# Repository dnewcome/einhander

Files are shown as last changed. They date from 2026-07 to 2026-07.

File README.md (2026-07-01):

# einhander

A one-handed hardware controller for music performance and sequencing — MC-303-inspired,
simplicity-first. Two rows of four key switches under the fingers, a thumbwheel + SHIFT on
the side for the thumb, so the other hand stays free for sliders/faders.

This repo holds the **code-driven** design: a parametric enclosure (build123d) and a
fabbable PCB (tscircuit → KiCad).

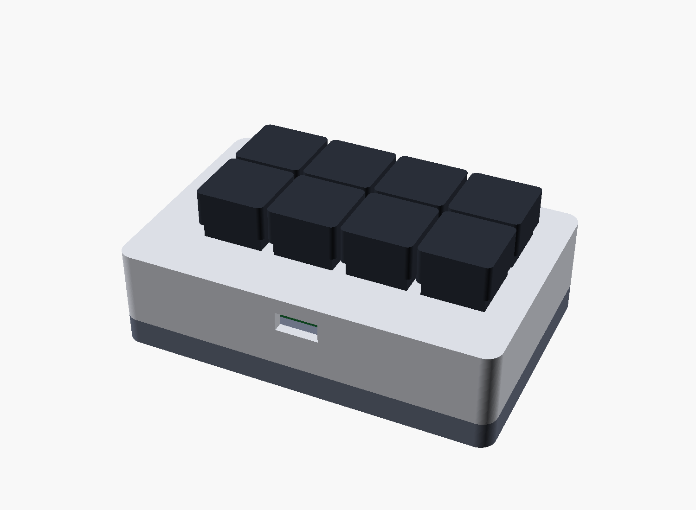
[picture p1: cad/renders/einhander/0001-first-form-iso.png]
einhander enclosure — isometric render


## What's here

```
cad/    parametric enclosure — build123d (machine_params.py = single source of truth),
        top/bottom shells + component stand-ins, assembly + dated render log
pcb/    RP2040 USB-MIDI controller board
          index.circuit.tsx        composes the board (flat, global nets)
          modules/                 mcu (RP2040+flash+xtal+decoupling), power (USB-C+LDO)
          lib/, imports/           shared params, custom Cherry-MX footprint, JLC parts
          scripts/                 route4.sh + the 4-layer routing toolchain
          index.circuit.kicad_pcb  routed 4-layer board
          fab/                     Gerbers + drill + CPL  (einhander-gerbers.zip → upload to JLCPCB)
```

## The board

- **RP2040**, pure **USB-MIDI** controller (class-compliant, no drivers), wired USB-C
- 8 MX key switches on direct GPIO; EC11 thumbwheel + SHIFT broken out to a header for a
  left-wall daughterboard; one WS2812 status LED; BOOTSEL/RESET
- **4-layer**: signals on outer layers, dedicated **GND + 3V3 inner planes**
- **DRC-clean**, ~91 × 68 mm

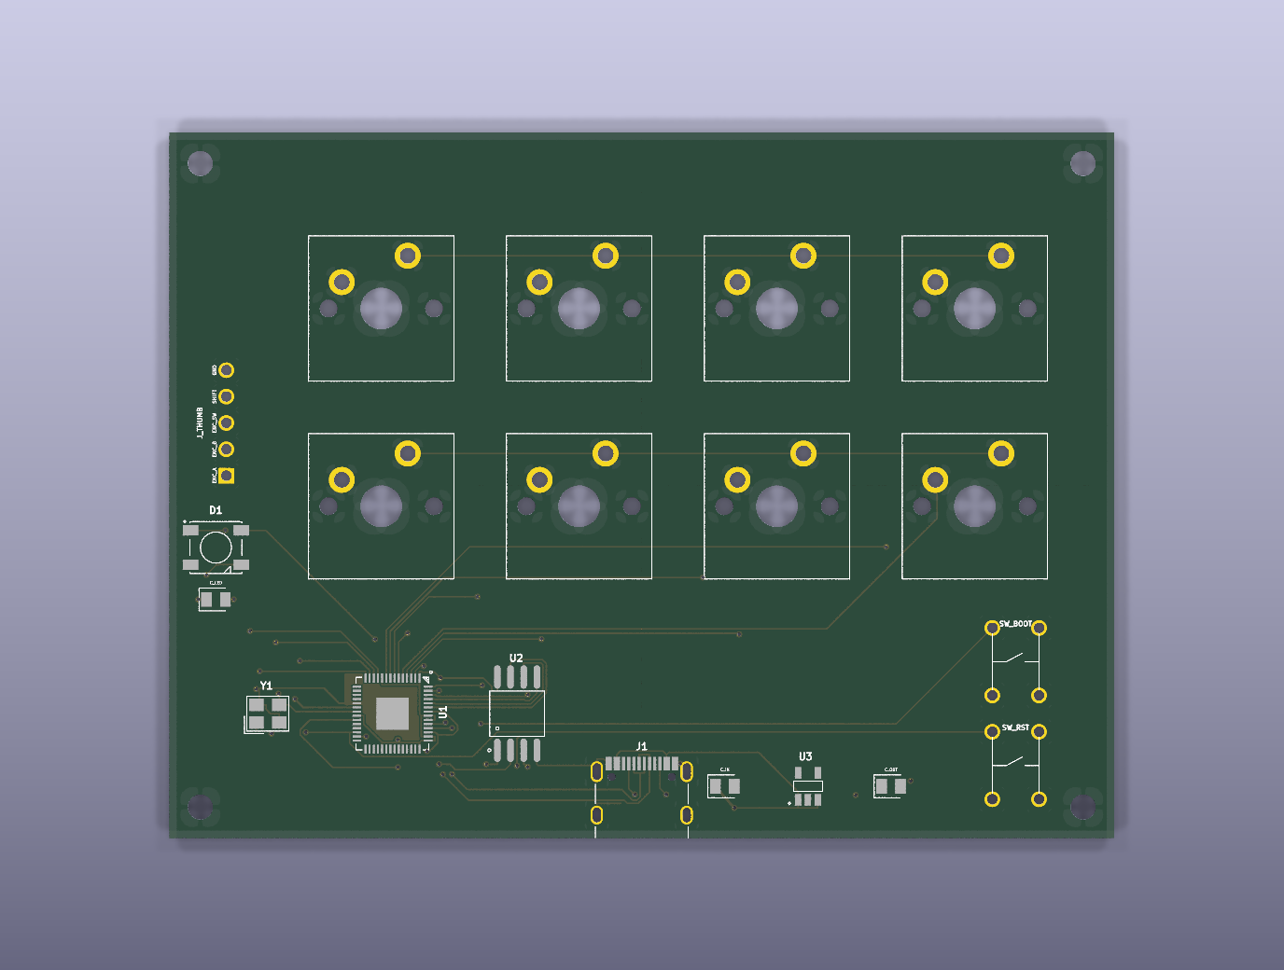
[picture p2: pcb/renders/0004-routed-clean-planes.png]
Routed 4-layer PCB


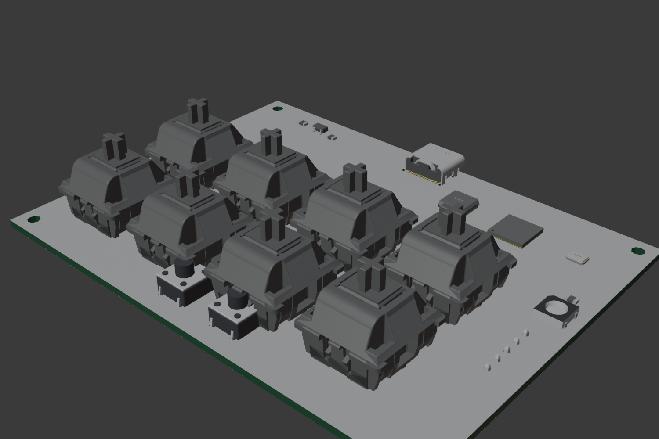
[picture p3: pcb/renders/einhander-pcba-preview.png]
Populated board (PCBA) with Cherry MX switches


Interactive 3D model of the populated board: **`pcb/renders/einhander-pcba.glb`** (open in any glTF viewer — Blender, VS Code glTF, or https://gltf-viewer.donmccurdy.com).

### Fabricating it

Upload `pcb/fab/einhander-gerbers.zip` to [JLCPCB](https://jlcpcb.com) (select **4 layers**). For
assembly, add `pcb/fab/einhander-bom.csv` (27 SMD parts, LCSC-mapped) + `pcb/fab/einhander-cpl.csv`
(placement). MX switches, the EC11 thumbwheel, headers, and BOOT/RESET tactiles are **hand-soldered**
(listed separately in `einhander-handsolder.csv`, kept out of the assembly BOM).

**PCBWay** uses the same `einhander-gerbers.zip` + `einhander-cpl.csv`, with `einhander-bom-pcbway.csv`
(sources by manufacturer part number instead of LCSC). `make_fab.sh` emits both BOM formats. Regenerate the whole bundle with `bash pcb/scripts/make_fab.sh pcb/index.circuit.kicad_pcb einhander`.

### Regenerating

```bash
# enclosure
cd cad && python3 machine.py            # STLs + renders

# PCB (needs bun/tscircuit, KiCad 9, Freerouting v2.2.4 + JDK 25)
cd pcb && npm install
bash scripts/route4.sh                  # export → route (4-layer) → inject → DRC
```

## Status

Enclosure prototype ✅ · Routed 4-layer PCB ✅ (fab-ready) · thumb-cluster daughterboard, RP2040
firmware (TinyUSB MIDI), and an enclosure↔board fit re-sync are next.

---
Designed with [Claude Code](https://claude.com/claude-code).

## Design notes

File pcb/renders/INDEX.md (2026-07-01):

- 0001-placement.png — 2026-06-30 — first valid placement (RP2040 USB-MIDI controller)
- 0002-routed-4layer.png — 2026-06-30 — 4-layer routed (v2.2.4): 256 wires, inner GND/V3V3 planes
- 0003-routed-clean.png — 2026-06-30 — CLEAN DRC (0 shorts/unconn), 4-layer
- 0004-routed-clean-planes.png — 2026-07-01 — 4-layer clean: GND/V3V3 planes, RP2040 local GND pour, NPTH keepouts (no traces through keyswitch holes), DRC clean

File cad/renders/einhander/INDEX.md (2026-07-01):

- 0001-first-form — 2026-06-30 — first-form

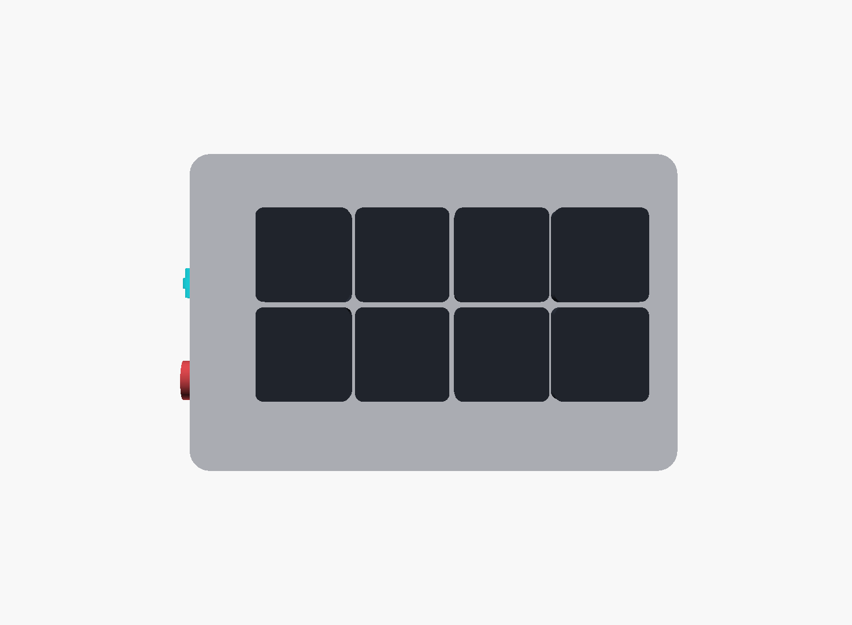
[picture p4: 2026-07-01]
cad/renders/einhander/0001-first-form-top.png

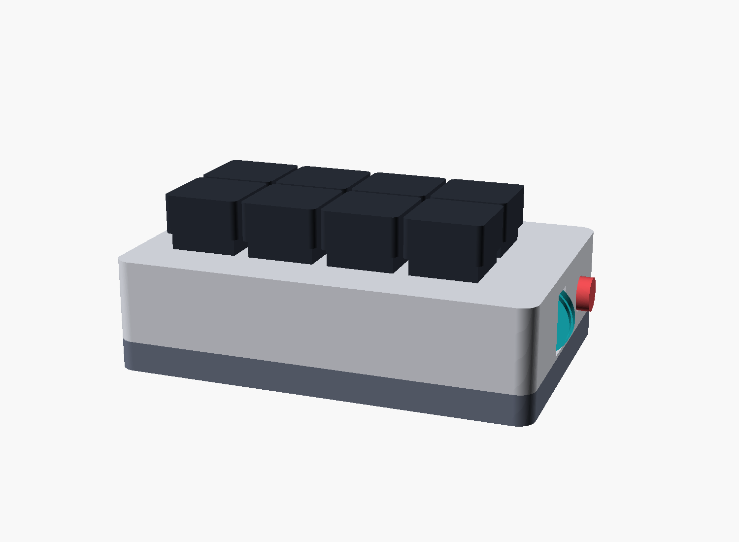
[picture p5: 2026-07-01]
cad/renders/einhander/0001-first-form-thumb.png

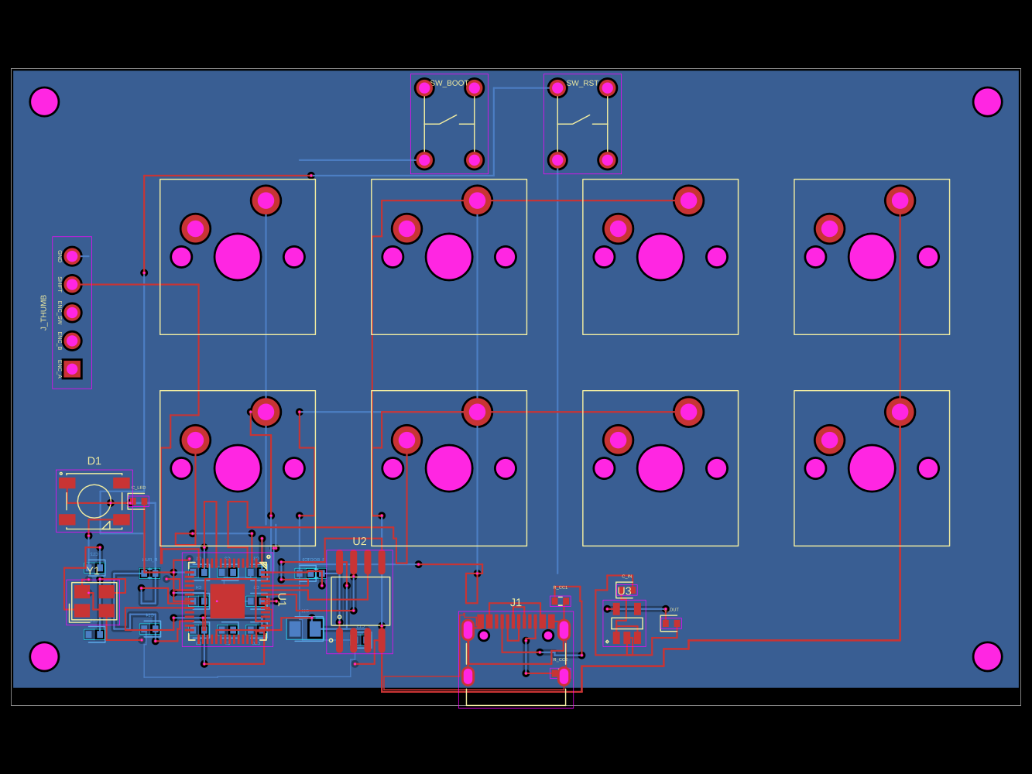
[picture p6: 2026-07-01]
pcb/renders/0001-placement.png

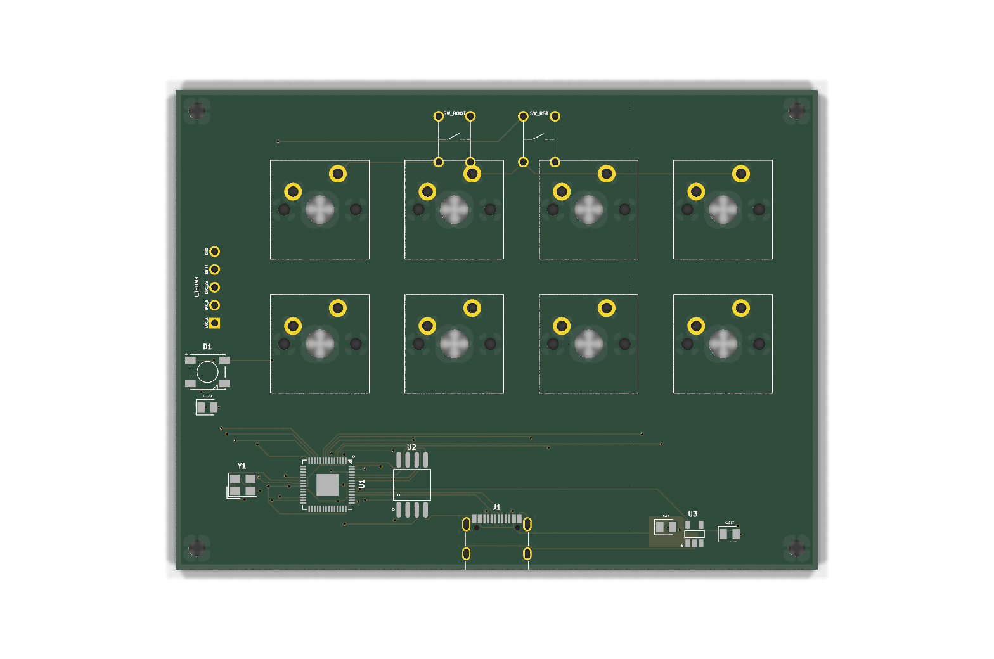
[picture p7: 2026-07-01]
pcb/renders/0003-routed-clean.png

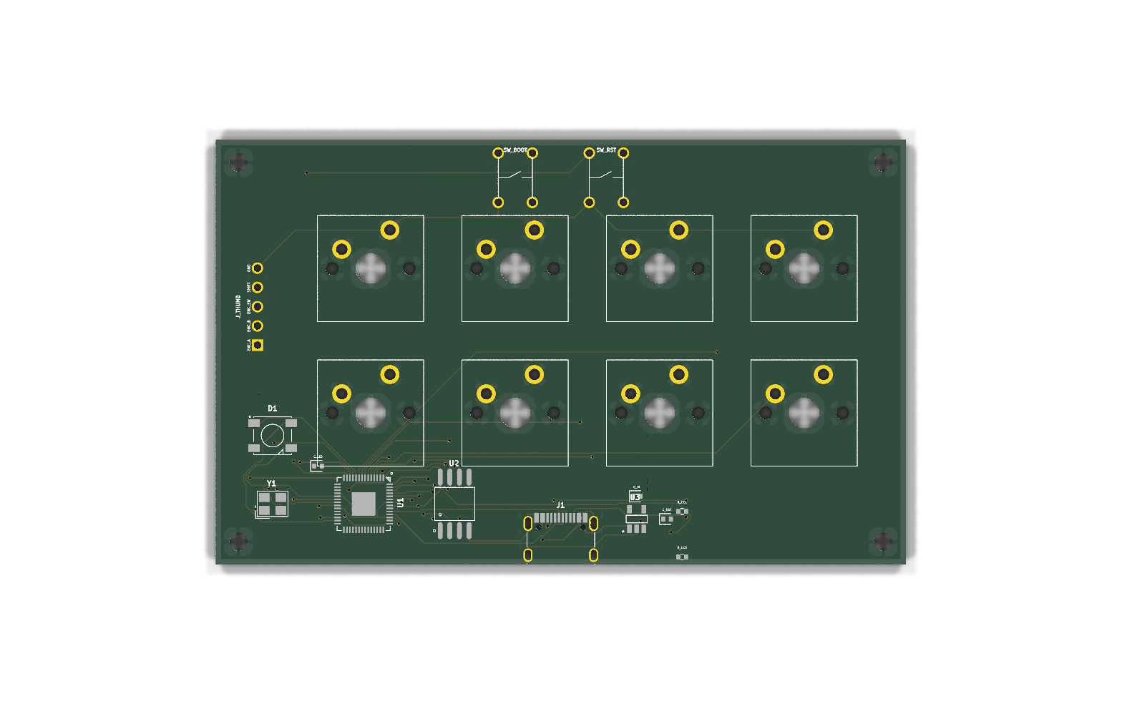
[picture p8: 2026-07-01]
pcb/renders/0002-routed-4layer.png

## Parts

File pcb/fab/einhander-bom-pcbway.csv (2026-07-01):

Item# | Designator | Qty | Comment | Footprint | Manufacturer Part Number | Manufacturer | LCSC Part No
1 | C1,C10,C14,C15,C2,C3,C4,C5,C6,C7 | 10 | 100nF | capacitor_0402 | CL05B104KO5NNNC | Samsung Electro-Mechanics | C1525
2 | C11 | 1 | 10uF | capacitor_0805 | CL21A106KAYNNNE | Samsung Electro-Mechanics | C15850
3 | C12,C13 | 2 | 15pF | capacitor_0402 | 0402CG150J500NT | FH (Guangdong Fenghua) | C1548
4 | C9 | 1 | 1uF | capacitor_0402 | CL05A105KA5NQNC | Samsung Electro-Mechanics | C52923
5 | C_LED | 1 | 100nF | capacitor_0805 | CC0805KRX7R9BB104 | YAGEO | C49678
6 | C_IN,C_OUT | 2 | 1uF | capacitor_0805 | CL21B105KBFNNNE | Samsung Electro-Mechanics | C28323
7 | D1 | 1 | WS2812B_B_T | WS2812B_B_T | WS2812B-B/T | Worldsemi | C2761795
8 | J1 | 1 | TYPE_C_31_M_12 | TYPE_C_31_M_12 | TYPE-C-31-M-12 | Korean Hroparts Elec | C165948
9 | R_RUN | 1 | 10k | resistor_res0402 | 0402WGF1002TCE | UNI-ROYAL(Uniroyal Elec) | C25744
10 | R_BOOT | 1 | 1k | resistor_res0402 | 0402WGF1001TCE | UNI-ROYAL(Uniroyal Elec) | C11702
11 | R_CC1,R_CC2 | 2 | 5.1k | resistor_res0402 | 0402WGF5101TCE | UNI-ROYAL(Uniroyal Elec) | C25905
12 | U1 | 1 | RP2040 | RP2040 | RP2040 | Raspberry Pi | C2040
13 | U2 | 1 | W25Q16JVSSIQ | W25Q16JVSSIQ | W25Q16JVSSIQ | Winbond | C131025
14 | U3 | 1 | AP2112K_3_3TRG1 | AP2112K_3_3TRG1 | AP2112K-3.3TRG1 | Diodes Incorporated | C51118
15 | Y1 | 1 | X322512MSB4SI | X322512MSB4SI | X322512MSB4SI | YXC | C9002

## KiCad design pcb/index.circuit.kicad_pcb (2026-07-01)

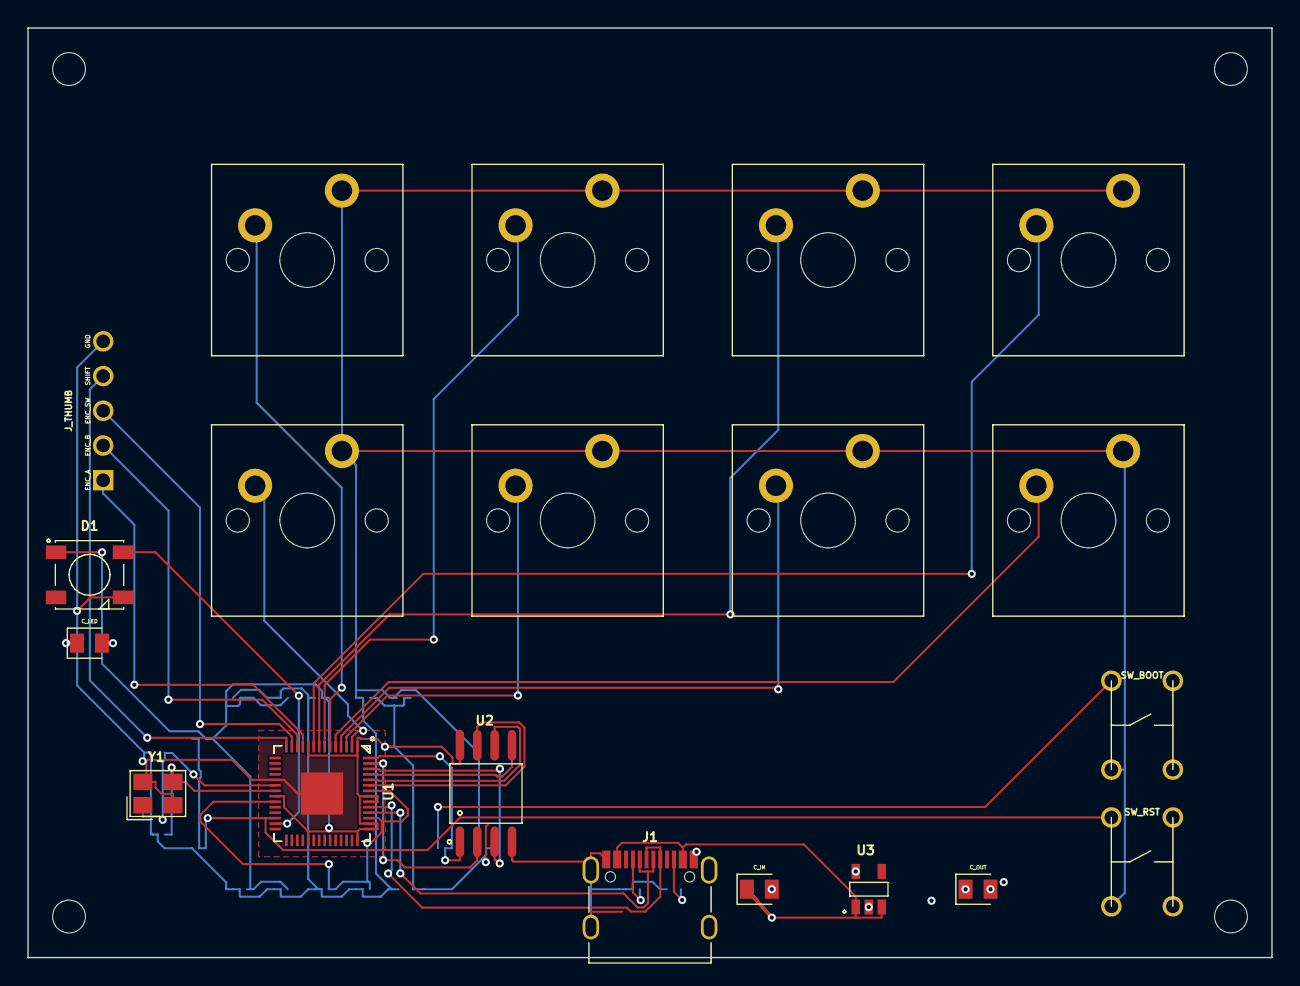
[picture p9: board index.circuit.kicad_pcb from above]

Board: 4 copper layers, 91.0 x 68.0 mm, 38 parts (0 on the bottom side), 31 nets.

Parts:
C1, C2, C3, C4, C5, C6, C7, C10, C14, C15: 100nF; capacitor_0402
C9: 1uF; capacitor_0402
C11: 10uF; capacitor_0805
C12, C13: 15pF; capacitor_0402
C_IN: 1uF; capacitor_0805
C_LED: 100nF; capacitor_0805
C_OUT: 1uF; capacitor_0805
D1: WS2812B_B_T
J1: TYPE_C_31_M_12
J_THUMB: J_THUMB; pin_header_pinrow5
R_BOOT: 1kΩ; resistor_res0402
R_CC1, R_CC2: 5.1kΩ; resistor_res0402
R_RUN: 10kΩ; resistor_res0402
SW1, SW2, SW3, SW4, SW5, SW6, SW7, SW8: chip
SW_BOOT: SW_BOOT; push_button_pushbutton
SW_RST: SW_RST; push_button_pushbutton
U1: RP2040
U2: W25Q16JVSSIQ
U3: AP2112K_3_3TRG1
Y1: X322512MSB4SI

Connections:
BOOT_BTN: R_BOOT.2, SW_BOOT.1
DVDD: C9.1, C10.1, U1.23, U1.45, U1.50
ENC_A: J_THUMB.1, U1.11
ENC_B: J_THUMB.2, U1.12
ENC_SW: J_THUMB.3, U1.13
GND: C1.2, C2.2, C3.2, C4.2, C5.2, C6.2, C7.2, C9.2, C10.2, C11.2, C12.2, C13.2, C14.2, C15.2, C_IN.2, C_LED.2, C_OUT.2, D1.3, J1.1, J1.2, J1.3, J1.4, J1.13, J1.14, J_THUMB.5, R_CC1.2, R_CC2.2, SW1.2, SW2.2, SW3.2, SW4.2, SW5.2, SW6.2, SW7.2, SW8.2, SW_BOOT.2, SW_RST.2, U1.19, U1.57, U2.4, U3.2, Y1.2, Y1.4
J1.A5 to R_CC1.pin1: J1.6, R_CC1.1
J1.B5 to R_CC2.pin1: J1.12, R_CC2.1
KEY0: SW1.1, U1.2
KEY1: SW2.1, U1.3
KEY2: SW3.1, U1.4
KEY3: SW4.1, U1.5
KEY4: SW5.1, U1.6
KEY5: SW6.1, U1.7
KEY6: SW7.1, U1.8
KEY7: SW8.1, U1.9
LED_DIN: D1.4, U1.27
QSPI_SCLK: U1.52, U2.6
QSPI_SD0: U1.53, U2.5
QSPI_SD1: U1.55, U2.2
QSPI_SD2: U1.54, U2.3
QSPI_SD3: U1.51, U2.7
QSPI_SS: R_BOOT.1, U1.56, U2.1
RUN: C14.1, R_RUN.2, SW_RST.1, U1.26
SHIFT: J_THUMB.4, U1.14
USB_DM: J1.7, J1.9, U1.46
USB_DP: J1.8, J1.10, U1.47
V3V3: C1.1, C2.1, C3.1, C4.1, C5.1, C6.1, C7.1, C11.1, C15.1, C_LED.1, C_OUT.1, D1.1, R_RUN.1, U1.1, U1.10, U1.22, U1.33, U1.42, U1.43, U1.44, U1.48, U1.49, U2.8, U3.5
VBUS: C_IN.1, J1.15, J1.16, U3.1, U3.3
XIN: C12.1, U1.20, Y1.1
XOUT: C13.1, U1.21, Y1.3

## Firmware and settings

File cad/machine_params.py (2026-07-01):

"""einhander — one-handed groovebox / MIDI controller.

SINGLE SOURCE OF TRUTH for every shared dimension + the place() mate helper.
Nothing downstream re-types a number that lives here.

Coordinate convention (world frame, right-handed device):
    +X = across the four fingers (column direction). Right = pinky side.
    +Y = "front" (away from palm, where the fingertips reach).
    -Y = "back"  (palm / wrist side).
    +Z = up (out of the top deck).
    World z=0 = underside of the bottom tray. Device grows upward.

Grip model: held in the right hand like a bar. Four fingers curl over the
back edge onto the 2x4 key deck (one column per finger, near/far per row).
The thumb wraps the LEFT (-X) wall and works the thumbwheel + SHIFT button.
"""

from math import sqrt
from build123d import Location, Pos, Rot  # noqa: F401  (re-exported for parts)


def place(solid, frm: Location, onto: Location):
    """Snap `solid` so its local mate `frm` coincides with world Location `onto`."""
    return (onto * frm.inverse()) * solid


# ---------------------------------------------------------------- key matrix
KEY_COLS = 4            # across the fingers (X)
KEY_ROWS = 2            # near / far per finger (Y)
KEY_PITCH = 19.05       # MX standard 0.75"
KEY_CUTOUT = 14.0       # MX plate cutout (square)
KEYCAP = 18.0           # 1u keycap footprint
KEYCAP_H = 9.0          # keycap height above deck
SWITCH_BODY = 15.6      # MX upper housing
SWITCH_BELOW = 5.0      # housing depth below deck top -> sets PCB plane

# center-to-center span of the matrix
KEYFIELD_X = (KEY_COLS - 1) * KEY_PITCH      # 57.15
KEYFIELD_Y = (KEY_ROWS - 1) * KEY_PITCH      # 19.05

# ---------------------------------------------------------------- body / shell
MARGIN_L = 12.0   # left (thumb) margin: keycap edge -> inner wall (wheel room)
MARGIN_R = 5.0    # right (pinky) margin
MARGIN_F = 9.0    # front margin
MARGIN_B = 24.0   # back (palm) margin — enlarged for the MCU band / routing room
WALL = 2.5
DECK_T = 1.5      # top plate thickness (MX snap-fit needs ~1.5)
FLOOR_T = 2.0

# inner cavity, centered on the body origin
CAV_X = KEYFIELD_X + KEYCAP + MARGIN_L + MARGIN_R
CAV_Y = KEYFIELD_Y + KEYCAP + MARGIN_F + MARGIN_B
BODY_X = CAV_X + 2 * WALL
BODY_Y = CAV_Y + 2 * WALL

# the matrix is pushed off-center so the thumb side gets the extra room
KEY_CENTER_X = (MARGIN_L - MARGIN_R) / 2.0   # +ve -> matrix shifts toward pinky
KEY_CENTER_Y = (MARGIN_B - MARGIN_F) / 2.0   # +ve -> matrix shifts toward front

# ---------------------------------------------------------------- heights
H_TOTAL = 26.0                     # shell height (keycaps extra)
SEAM_Z = 7.0                       # split plane: bottom tray height
H_BOT = SEAM_Z                     # bottom shell height
H_TOP = H_TOTAL - SEAM_Z           # top shell height (19)

DECK_TOP_Z = H_TOTAL                       # world z of deck top face
DECK_UNDER_Z = H_TOTAL - DECK_T            # 24.5
PCB_T = 1.6
PCB_TOP_Z = DECK_UNDER_Z - SWITCH_BELOW    # 19.5  (switch sits on plate, solders to PCB)
PCB_BOT_Z = PCB_TOP_Z - PCB_T


def key_xy(col, row):
    """World (x, y) of a switch center."""
    x = KEY_CENTER_X + (col - (KEY_COLS - 1) / 2.0) * KEY_PITCH
    y = KEY_CENTER_Y + (row - (KEY_ROWS - 1) / 2.0) * KEY_PITCH
    return x, y


KEY_XY = [key_xy(c, r) for r in range(KEY_ROWS) for c in range(KEY_COLS)]

# ---------------------------------------------------------------- thumb cluster (left wall)
WHEEL_R = 8.0          # dia 16 thumbwheel
WHEEL_T = 6.0          # rim width (along Y)
WHEEL_PROTRUDE = 2.5   # how far the rim pokes past the outer wall (-X)
WHEEL_Y = 6.0          # toward front
WHEEL_Z = 15.0         # mid-height
# wheel axis runs along Y (front-back); thumb rolls it up/down through a side slot
WHEEL_CX = -BODY_X / 2 + (WHEEL_R - WHEEL_PROTRUDE)   # disc center x (inside)

# slot in the left wall: narrow in Y (rim width), tall in Z (exposed chord)
WHEEL_SLOT_W = WHEEL_T + 1.5
WHEEL_SLOT_H = 2 * sqrt(WHEEL_R**2 - (WHEEL_R - WHEEL_PROTRUDE) ** 2) + 2.5

BTN_D = 8.0            # SHIFT button cap diameter
BTN_Y = -14.0          # toward back (palm); thumb slides wheel<->button along Y
BTN_Z = 15.0

# ---------------------------------------------------------------- USB-C (back wall)
USB_W = 11.0
USB_H = 5.0
USB_X = 0.0
USB_Z = PCB_TOP_Z      # connector body rides on top of the PCB

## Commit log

2026-07-01 einhander: parametric enclosure + routed 4-layer RP2040 USB-MIDI PCB
    One-handed music controller (2x4 keys + thumbwheel). Includes the build123d
    enclosure prototype and a DRC-clean 4-layer PCB (RP2040, inner GND/3V3 planes)
    with JLCPCB-ready fab outputs, plus the 4-layer Freerouting toolchain.
    [einhander-cpl.csv, index.circuit-B_Courtyard.gbr, index.circuit-B_Cu.gbl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]
2026-07-01 README: add enclosure isometric + routed PCB renders
2026-07-01 Add BOM + reusable fab-bundle scripts (gerbers/drill/CPL/BOM)
    gen_bom.py maps LCSC part numbers (ICs from imports, passives from JLC basic
    parts) and flags hand-solder parts. make_fab.sh produces the full JLCPCB upload
    bundle. einhander-bom.csv: 27 assembled + 11 hand-solder parts.
    [einhander-bom.csv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]
2026-07-01 Fix JLCPCB BOM + CPL format (error processing BOM)
    BOM: JLC's exact 4 columns, ASCII only (10k not 10k�), assembled parts only —
    hand-solder parts split to einhander-handsolder.csv. CPL: remap to JLC columns
    (Designator, Mid X/Y, Layer, Rotation) and drop empty-designator hole rows.
    [einhander-bom.csv, einhander-handsolder.csv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]
2026-07-01 Add PCBWay support to fab bundle (MPN-sourced BOM)
    make_fab.sh <board> [name] [jlcpcb|pcbway|both] now emits both BOM formats;
    Gerbers + CPL are shared. gen_bom.py --fab pcbway outputs Manufacturer Part
    Number + Manufacturer + LCSC columns (PCBWay sources by MPN, not LCSC).
    [einhander-bom-pcbway.csv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]
2026-07-01 Add PCBA GLB 3D model + filter CPL to assembled parts
    tsci export -f glb -> pcb/renders/einhander-pcba.glb (populated board, component
    3D models). make_fab.sh now filters the CPL to the BOM's designators so JLC no
    longer warns about placed-but-unsourced hand-solder parts.
    [einhander-cpl.csv, index.circuit-B_Courtyard.gbr, index.circuit-B_Cu.gbl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]
2026-07-01 Add Cherry MX 3D models to keyswitches + PCBA preview render
    lib/KeySwitch.tsx now carries the EasyEDA Cherry MX cadModel (C3316924);
    our footprint origin is at the switch center so no Y offset is needed. GLB
    re-exported with 8 switch models placed on the grid; Blender full-board
    preview render added.
2026-07-01 Add Makefile + committed GLB render script (regenerate cad/glb/fab/render)
    make targets: cad, glb, render, fab, route, all, clean. render_glb.py moved
    into pcb/scripts/ so `make render` regenerates the GLB + Blender preview.
    [index.circuit-B_Courtyard.gbr, index.circuit-B_Cu.gbl, index.circuit-B_Fab.gbr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]
2026-07-01 pcb: fabricable 4-layer route — NPTH keepouts, GND/V3V3 planes, RP2040 pour
    The prior route was not fabricable: 11 signal traces crossed keyswitch/USB
    mounting holes (open nets), GND/V3V3 snaked as ~250 tracks on the signal
    layers, and two decaps were floating (top pad, back-layer traces, no via).
    Re-routed through a corrected pipeline; final DRC is clean (0 shorts /
    0 crossings / 0 unconnected / 0 courtyard overlaps).
    Routing pipeline (scripts/route4.sh):
    - add_npth_keepouts.py: keepout every non-plated mechanical hole (keyswitch
    poles/pins, USB posts, screw holes) so no trace crosses a drilled hole —
    add_cutout_keepouts.py only covers Edge.Cuts, not pad-holes.
    - keep GND/V3V3 in t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
    [einhander-cpl.csv, index.circuit-B_Courtyard.gbr, index.circuit-B_Cu.gbl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]
2026-07-01 pcb: fix JLC DFM hole-spacing — reroute J1.14 ground fanout off the mount hole
    JLCPCB DFM flagged a plated-hole spacing danger: a GND fanout via sat 0.041 mm
    from J1's 1.6 mm USB-C mounting hole (< the 0.5 mm hole-to-hole minimum).
    J1.14 (SMD ground pad) now fans out through a via placed clear of both the
    mount hole and the VBUS trace; closest non-connector hole spacing is 0.537 mm.
    DRC stays clean (0 shorts / 0 unconnected). Regenerated fab bundle.
    New helpers: fix_hole_spacing.py (delete finisher vias too close to a hole),
    reconnect_j14.py (re-fanout a pad clear of holes + copper). Note: kipy's
    get_tracks() does NOT return vias — must use get_vias().
    Remaining DFM items are non-block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
    [index.circuit-B_Courtyard.gbr, index.circuit-B_Cu.gbl, index.circuit-B_Fab.gbr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]
2026-07-01 pcb: add dfm_check.py final gate to make_fab (fab rules DRC misses)
    The J1-via-in-mounting-hole DFM danger passed KiCad DRC because DRC doesn't
    enforce plated hole-to-hole spacing. dfm_check.py checks that (>=0.5 mm edge)
    plus via drill/annular minimums, splitting ACTIONABLE inter-part violations
    (reroute) from part-inherent intra-footprint ones (connector's own spacing),
    and skips silkscreen (cosmetic — JLC auto-clips). make_fab.sh runs it as
    step [0] before bundling. Regenerated fab bundle.
    [index.circuit-B_Courtyard.gbr, index.circuit-B_Cu.gbl, index.circuit-B_Fab.gbr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]
